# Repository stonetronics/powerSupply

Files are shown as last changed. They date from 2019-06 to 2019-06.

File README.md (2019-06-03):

# powerSupply
voltage and current regulated power supply

this is a clone of a schematic found in an old 1982 elektor magazine + fan cooling and overtemperature protection

It uses a ua723 voltage regulator chip for voltage reference and two ua741 for voltage and current limiting and regulation
Furthermore, it is designed to either screw TO-220 transistors on the pcb to a heatsink or clamp on a completely seperate "power-transistor pack"
There can be a NTC thermistor screwed into the heatsink, which is used for fan control and overtemperature protection, which is handled by a tl084

!!Moved Mechanical to thingiverse

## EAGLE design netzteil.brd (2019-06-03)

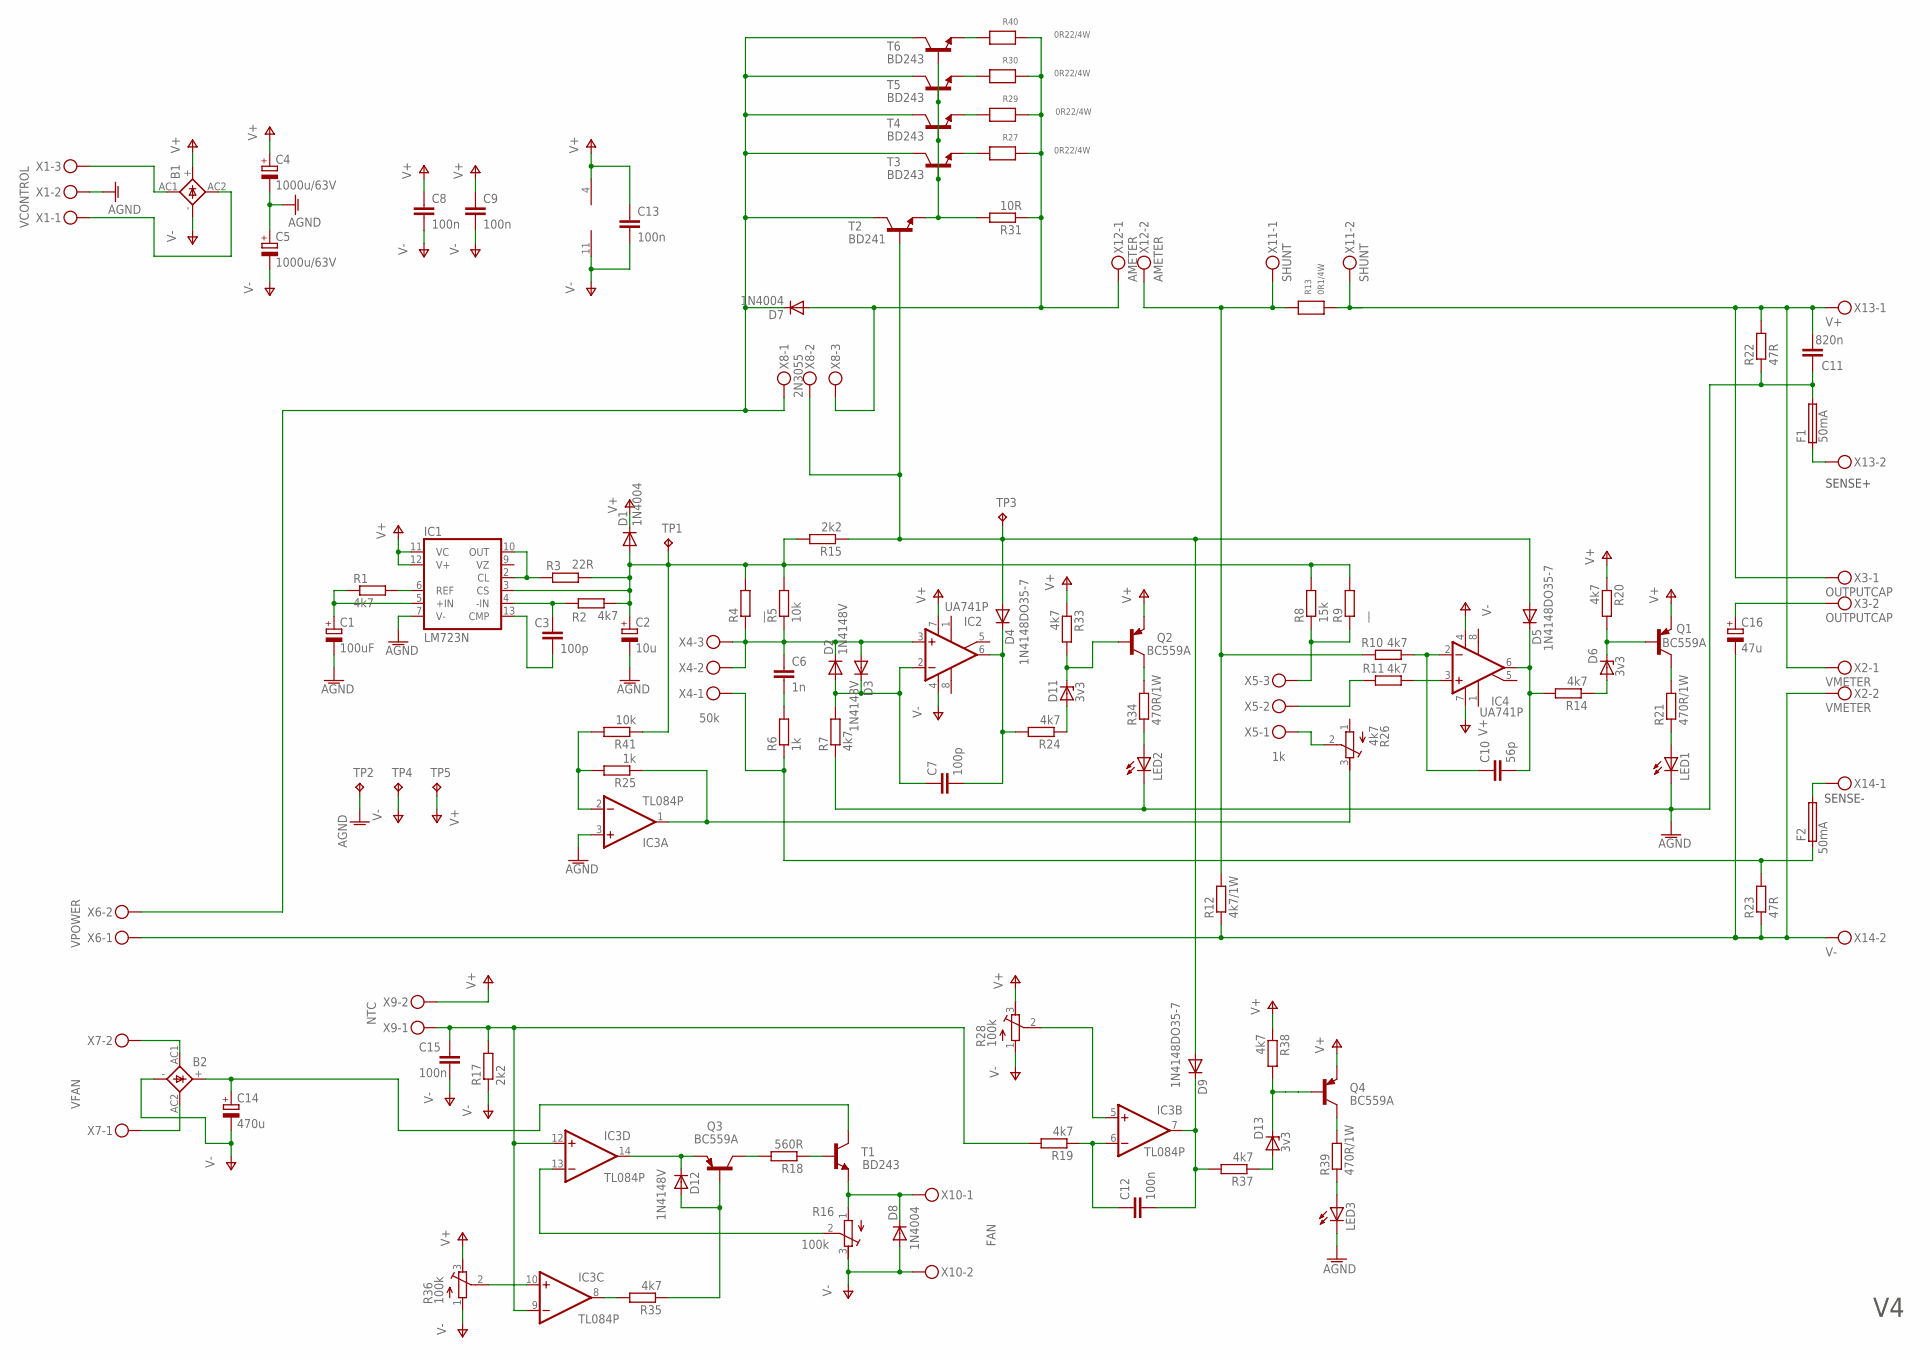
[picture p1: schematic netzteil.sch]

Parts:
B1, B2: 1KAB
C1: 100uF; E3,5-8
C2: 10u; E3,5-8
C3, C7: 100p; C025-025X050
C4, C5: 1000u/63V; E7,5-18
C6: 1n; C025-025X050
C8, C9, C12, C13, C15: 100n; C025-025X050
C10: 56p; C025-025X050
C11: 820n; C025-025X050
C14: 470u; E5-13
C16: 47u; E3,5-8
D1, D7, D8: 1N4004; DO41-10
D2, D3, D12: 1N4148V; SHORTDIODE
D4, D5, D9: 1N4148DO35-7; DO35-7
D6, D11, D13: 3v3; SHORTDIODE
F1, F2: 50mA; PICOFUSE
IC1: LM723N; DIL14
IC2, IC4: UA741P; DIL08
IC3: TL084P; DIL14
LED1, LED2, LED3: LED3MM
Q1, Q2, Q3, Q4: BC559A; TO92-EBC
R1, R2, R7, R10, R11, R14, R20, R24, R33, R35, R37, R38: 4k7; 0207/2V
R3: 22R; 0207/2V
R4, R9: __; 0207/2V
R5, R41: 10k; 0207/2V
R6, R25: 1k; 0207/2V
R8: 15k; 0207/2V
R12: 4k7/1W; 0207/10
R13: 0R1/4W; 4W_RM15
R15: 2k2; 0207/7
R16, R28, R36: 100k; RTRIM3296Y
R17: 2k2; 0207/2V
R18: 560R; 0207/2V
R19: 4k7; 0207/7
R21, R34, R39: 470R/1W; 0207/2V
R22, R23: 47R; 0207/2V
R26: 4k7; RTRIM3296Y
R27, R29, R30, R40: 0R22/4W; 4W_RM15
R31: 10R; 0207/2V
T1, T3, T4, T5, T6: BD243; TO220V
T2: BD241; TO220V
TP1, TP2, TP3, TP4, TP5: TPPAD1-13; P1-13
X1: VCONTROL; MKDSN1,5/3-5,08
X2: VMETER; MKDSN1,5/2-5,08
X3: OUTPUTCAP; MKDSN1,5/2-5,08
X4: 50k; MKDSN1,5/3-5,08
X5: 1k; MKDSN1,5/3-5,08
X6: VPOWER; MKDSN1,5/2-5,08
X7: VFAN; MKDSN1,5/2-5,08
X8: 2N3055; MKDSN1,5/3-5,08
X9: NTC; MKDSN1,5/2-5,08
X10: FAN; MKDSN1,5/2-5,08
X11: SHUNT; MKDSN1,5/2-5,08
X12: AMETER; MKDSN1,5/2-5,08
X13: V+; MKDSN1,5/2-5,08
X14: V-; MKDSN1,5/2-5,08

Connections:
AGND: C1.-, C2.-, C4.-, C5.+, C11.1, F1.2, IC1.7 (V-), IC3.3 (+IN), LED1.K (C), LED2.K (C), LED3.K (C), R7.1, R22.1, TP2.TP, X1.2
unnamed: IC1.6 (REF), R1.2
unnamed: C1.+, IC1.5 (+IN), R1.1
unnamed: C6.1, D2.K (C), D3.A, IC2.3 (+IN), R4.1, R5.1, X4.2, X4.3
unnamed: C6.2, R6.2
unnamed: C3.1, IC1.4 (-IN), R2.1
unnamed: IC1.2 (CL), IC1.10 (OUT), R3.1
unnamed: IC3.2 (-IN), R25.2, R41.2
unnamed: C7.1, D2.A, D3.K (C), IC2.2 (-IN), R7.2
unnamed: C3.2, IC1.13 (CMP)
unnamed: C7.2, D4.C, IC2.6 (OUT), R24.2
unnamed: C10.1, IC4.2 (-IN), R10.1
unnamed: IC4.3 (+IN), R11.1
unnamed: R8.1, R9.1, X5.3
unnamed: R11.2, X5.2
unnamed: D4.A, D5.A, D9.A, R15.1, T2.1 (B), TP3.TP, X8.2
unnamed: C10.2, D5.C, IC4.6 (OUT), R14.2
unnamed: R10.2, R12.2, R13.P$1, X11.1, X12.2
unnamed: C11.2, R13.P$2, R22.2, X2.1, X3.1, X11.2, X13.1
unnamed: D7.A, R27.P$2, R29.P$2, R30.P$2, R31.1, R40.P$2, X8.3, X12.1
unnamed: D6.K (C), Q1.B, R20.2
unnamed: D11.K (C), Q2.B, R33.2
unnamed: D11.A, R24.1
unnamed: B1.AC1, X1.3
unnamed: B1.AC2, X1.1
unnamed: Q2.C, R34.2
unnamed: D6.A, R14.1
unnamed: Q1.C, R21.2
unnamed: LED1.A, R21.1
unnamed: D7.C, T2.2 (C), T3.2 (C), T4.2 (C), T5.2 (C), T6.2 (C), X6.2, X8.1
unnamed: F2.1, R6.1, R23.2, X4.1
unnamed: C16.-, R12.1, R23.1, X2.2, X6.1, X14.2
unnamed: R26.2 (S), X5.1
unnamed: IC3.1 (OUT), R25.1, R26.3 (E)
unnamed: LED2.A, R34.1
unnamed: C16.+, X3.2
unnamed: D12.K (C), IC3.14 (OUT), Q3.E
unnamed: Q3.C, R18.2
unnamed: D12.A, Q3.B, R35.1
unnamed: IC3.8 (OUT), R35.2
unnamed: IC3.10 (+IN), R36.2 (S)
unnamed: IC3.13 (-IN), R16.2 (S)
unnamed: C12.1, IC3.6 (-IN), R19.1
unnamed: F2.2, X14.1
unnamed: R18.1, T1.1 (B)
unnamed: IC3.5 (+IN), R28.2 (S)
unnamed: D8.C, R16.1 (A), T1.3 (E), X10.1
unnamed: C12.2, D9.C, IC3.7 (OUT), R37.2
unnamed: C15.1, IC3.9 (-IN), IC3.12 (+IN), R17.2, R19.2, X9.1
unnamed: R31.2, T2.3 (E), T3.1 (B), T4.1 (B), T5.1 (B), T6.1 (B)
unnamed: R27.P$1, T3.3 (E)
unnamed: R29.P$1, T4.3 (E)
unnamed: R30.P$1, T5.3 (E)
unnamed: B2.AC1, X7.2
unnamed: B2.AC2, X7.1
unnamed: B2.+, C14.+, T1.2 (C)
unnamed: D13.K (C), Q4.B, R38.2
unnamed: D13.A, R37.1
unnamed: Q4.C, R39.2
unnamed: LED3.A, R39.1
unnamed: F1.1, X13.2
unnamed: R40.P$1, T6.3 (E)
V723: C2.+, D1.A, IC1.3 (CS), R2.2, R3.2, R4.2, R5.2, R8.2, R9.2, R15.2, R41.1, TP1.TP
V+: B1.+, C4.+, C8.1, C9.1, C13.1, D1.C, IC1.11 (VC), IC1.12 (V+), IC2.7 (V+), IC3.4 (V+), IC4.7 (V+), Q1.E, Q2.E, Q4.E, R20.1, R28.3 (E), R33.1, R36.3 (E), R38.1, TP5.TP, X9.2
V-: B1.-, B2.-, C5.-, C8.2, C9.2, C13.2, C14.-, C15.2, D8.A, IC2.4 (V-), IC3.11 (V-), IC4.4 (V-), R16.3 (E), R17.1, R28.1 (A), R36.1 (A), TP4.TP, X10.2

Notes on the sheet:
SENSE-
SENSE+

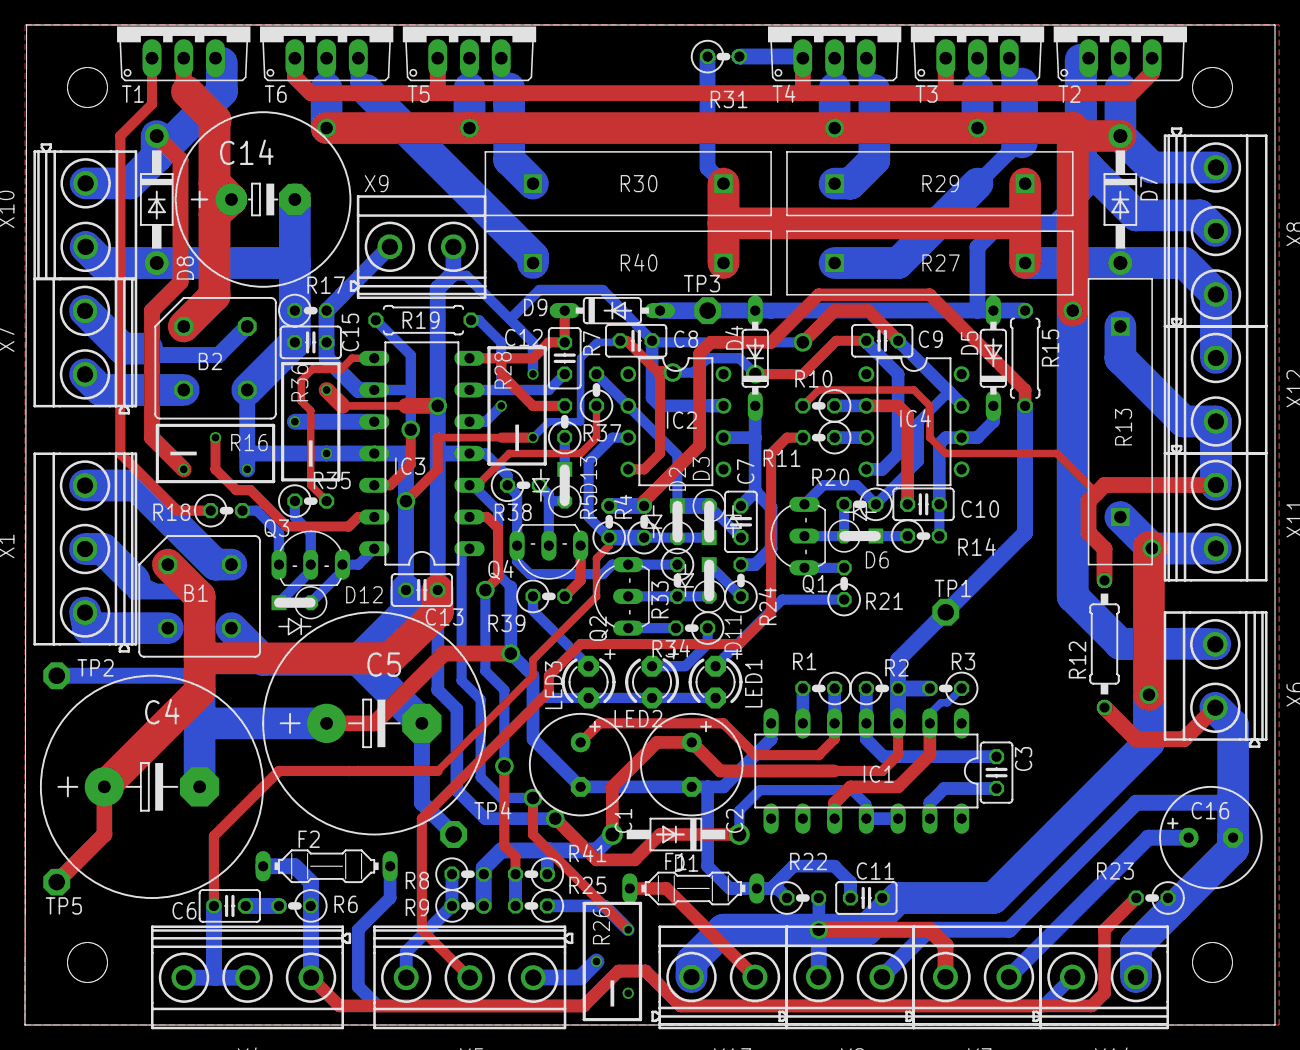
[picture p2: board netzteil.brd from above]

Board: 2 copper layers, 100.0 x 80.0 mm, 108 parts (0 on the bottom side), 65 nets.

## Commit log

2018-04-02 initial commit schematics and board
    [netzteil.brd, netzteil.sch]
2018-05-02 added minimum temperature enable for fan, fixed errors in regulation, adapted clamps for panel meters, added C.V. and overtemperature display diode, seperate supply for fan
    [netzteil.brd, netzteil.sch]
2018-05-13 added amperemeter and shunt clamps, semi-final version of the schematic for the pcb
    [netzteil.brd, netzteil.sch]
2018-05-13 repair commit
    [netzteil.brd, netzteil.sch]
2018-05-15 finished pre-final pcb layout
    [netzteil.brd, netzteil.sch]
2018-05-22 started housing for prototype 1
2018-05-23 work on housing for prototype 1
    [Housing_Prototype1.fcstd]
2018-05-24 almost finished housing for prototype 1
    [Housing_Prototype1.fcstd]
2019-03-29 moved mechanical to thingiverse
    [Housing_Prototype1.fcstd, netzteil.brd, netzteil.sch]
